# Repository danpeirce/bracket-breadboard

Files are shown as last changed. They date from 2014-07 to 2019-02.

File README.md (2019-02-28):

# PICkit2, PICkit3 Programming Header to Breadboard Bracket (Master Branch - Arms removed)

This version of the README.md file will be updated with new photos as they becom available.

## Purpose of the bracket-breadboard SCAD Project
In APSC1299 and PHYS1600 a six pin programming header must be attached to a solderless breadboard. In the past this has been done with hot glue as a quick simple solution. A better long term solution is desirable. The last time I needed a bracket I turned to having it 3D printed and was happy with the result. This project lends itself nicely to 3D printing because the bracket will be small with fine features.

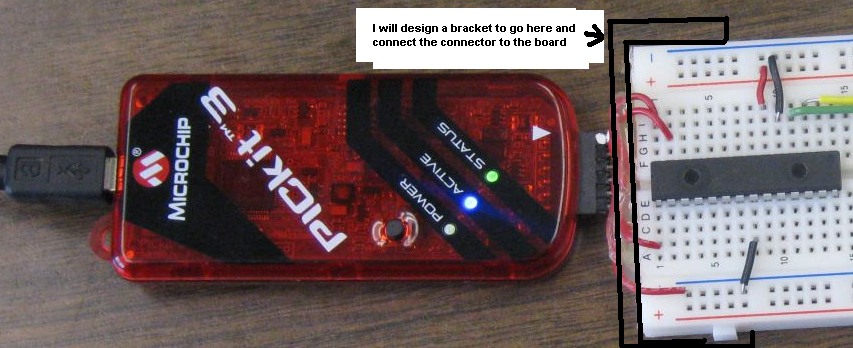
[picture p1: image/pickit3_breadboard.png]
PICkit2, PICkit3 Programming header to Breadboard Bracket


Final Version (to reduce cost attachment arms were left out)

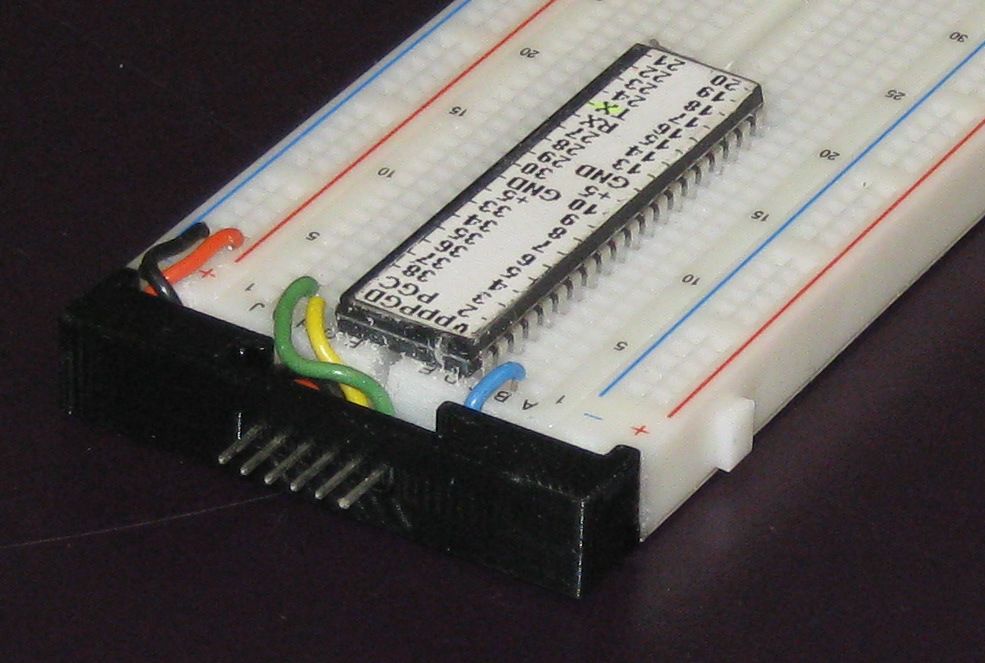
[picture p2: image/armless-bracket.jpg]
Image of final version without attachment arms


Image of prototype

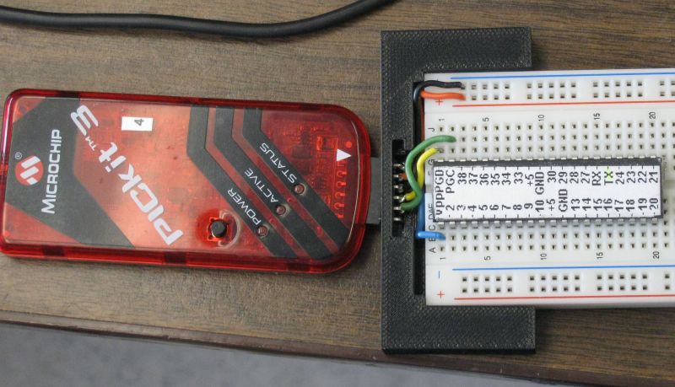
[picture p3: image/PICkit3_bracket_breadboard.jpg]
Bracket Top Back


## Creating a 3D Model using OpenSCAD

OpenSCAD is an free open source program that can be used for creating and viewing 3D models.

* [My notes on OpenSCAD including links](https://danpeirce.github.io/openscad.html)

### The Model

This image is from the second version of the SCAD file
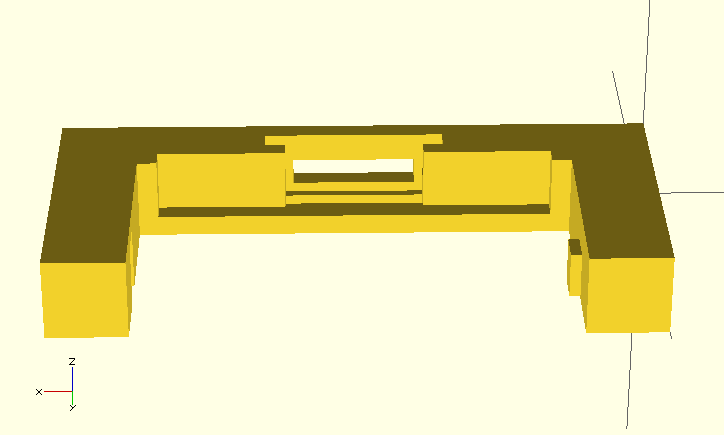
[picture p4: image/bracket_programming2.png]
bracket programming V2


These images are from the [first version of the SCAD file](https://github.com/danpeirce/bracket-breadboard/blob/c5ccfa7ed66dbcf597f41a93814c27feb3500029/bracket_programming.scad).

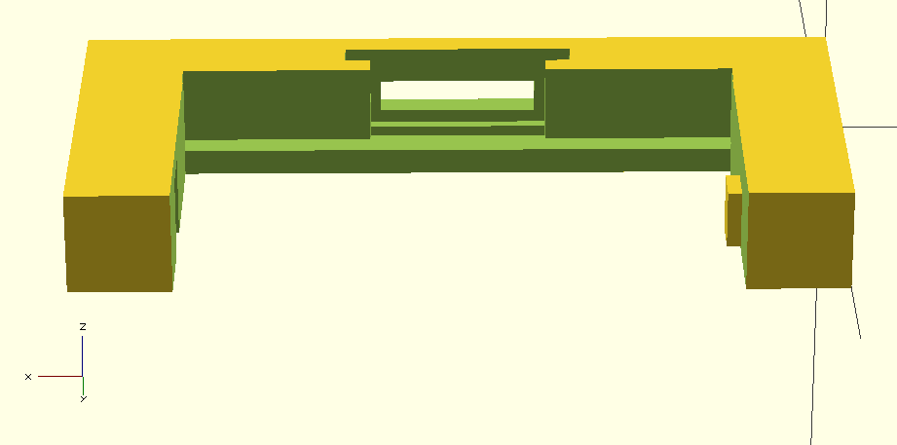
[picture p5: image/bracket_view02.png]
Bracket View 02


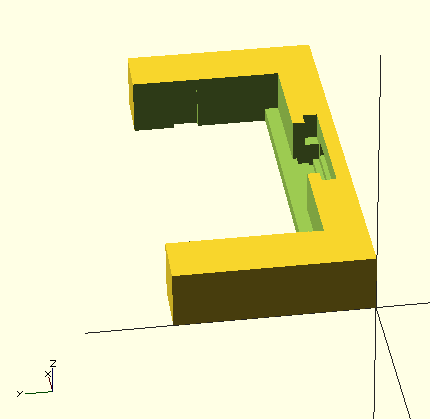
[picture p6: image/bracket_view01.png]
Bracket View 01


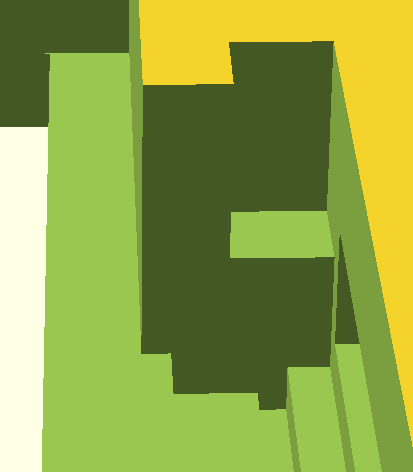
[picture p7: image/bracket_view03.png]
Bracket View 03


## Amended Procedure of adding Header and Wire

In 2016 the procedure for adding the header and wire was Amended to speed up the process.

In interest of keeping new programming header mounting method more time efficient and at the same time keeping 
the final result essentially unchanged I have worked out the following procedure/method (still using the existing 
3D printed part):

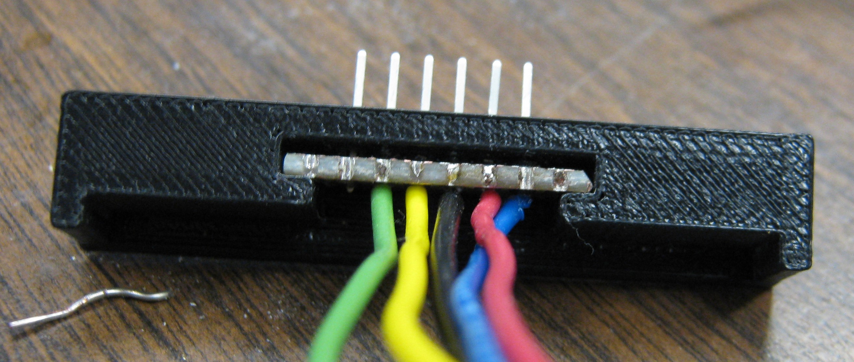
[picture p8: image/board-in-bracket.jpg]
board-in-bracket


I then mount it with hotglue so it can be removed the next time the breadbaord needs to be replaced:

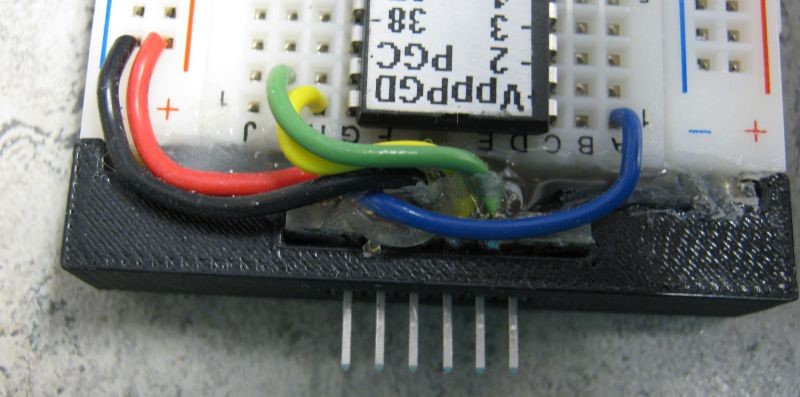
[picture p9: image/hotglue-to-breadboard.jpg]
hotglue-to-breadboard


The other change that helps get this together faster than before is the addition of a small piece of proto board 
and the change to straight header pins:

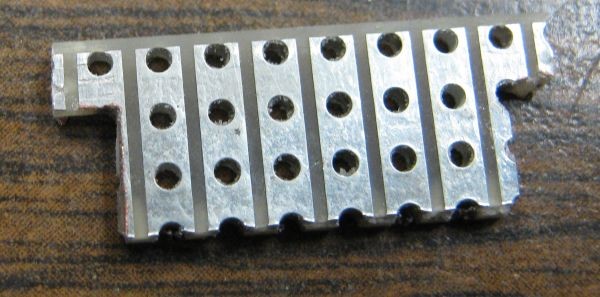
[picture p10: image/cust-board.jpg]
cust-board


* I solder the wires on first.
* Insert the header into the 3d printed addaptor.
* Then solder the header pins.

This way one can avoid twisting the wire onto each pin and crimping which is what I did before. 

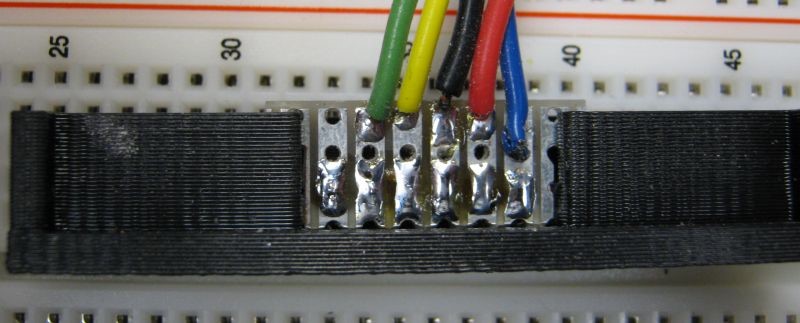
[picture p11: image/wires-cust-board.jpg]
wires-cust-board


## Prototype
 
These are the first images of the prototype that has been 3D printed in the KPU drafting department.
 
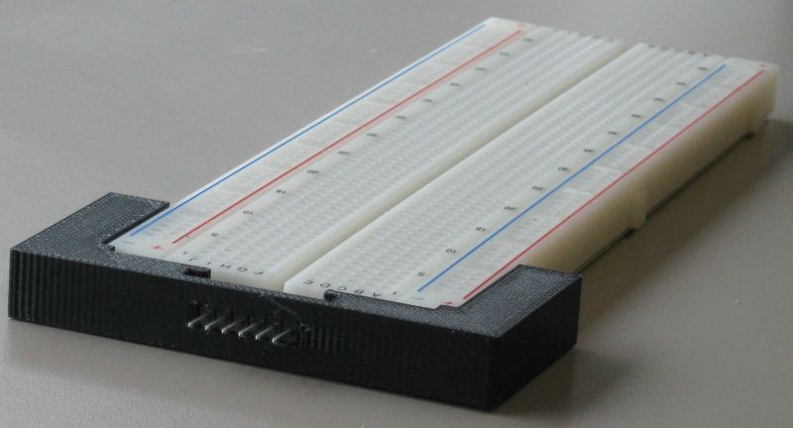
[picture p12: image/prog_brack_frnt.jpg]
Bracket Top Front


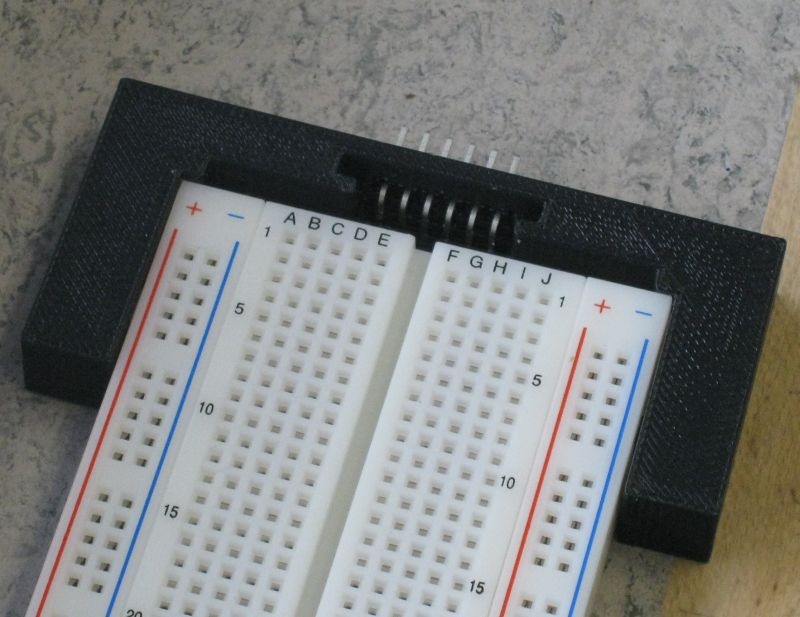
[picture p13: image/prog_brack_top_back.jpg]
Bracket Top Back
 

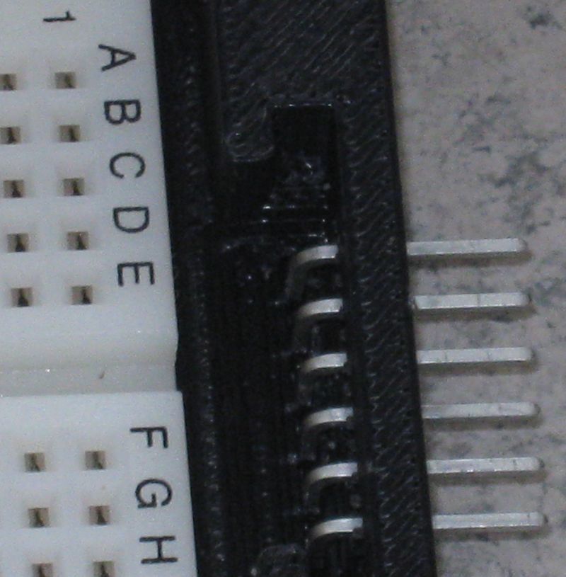
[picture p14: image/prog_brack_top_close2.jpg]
Connector Close2


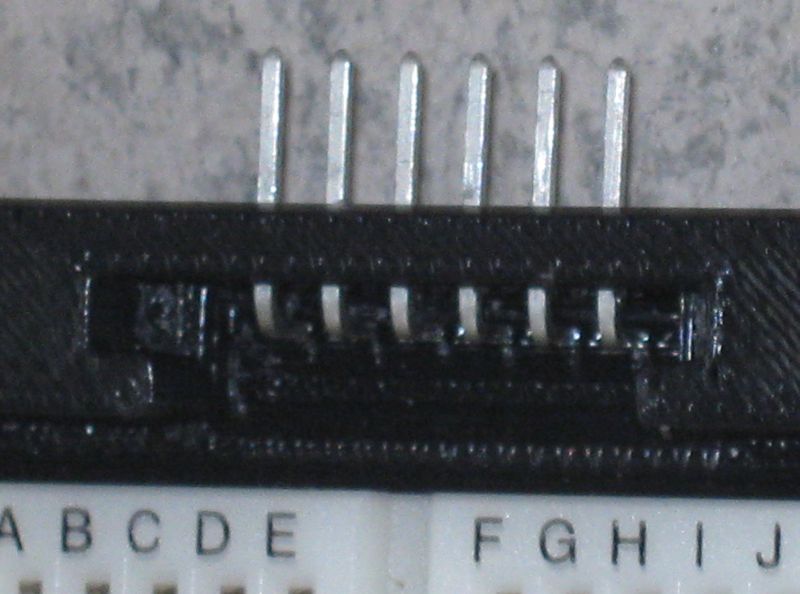
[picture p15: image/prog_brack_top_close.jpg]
Connector Close


## Soldering Wire Onto the Programming Header

The end of the hookup wire was bent in a loop and crimped onto the pins below the bend of in each pin. Solder was applied.

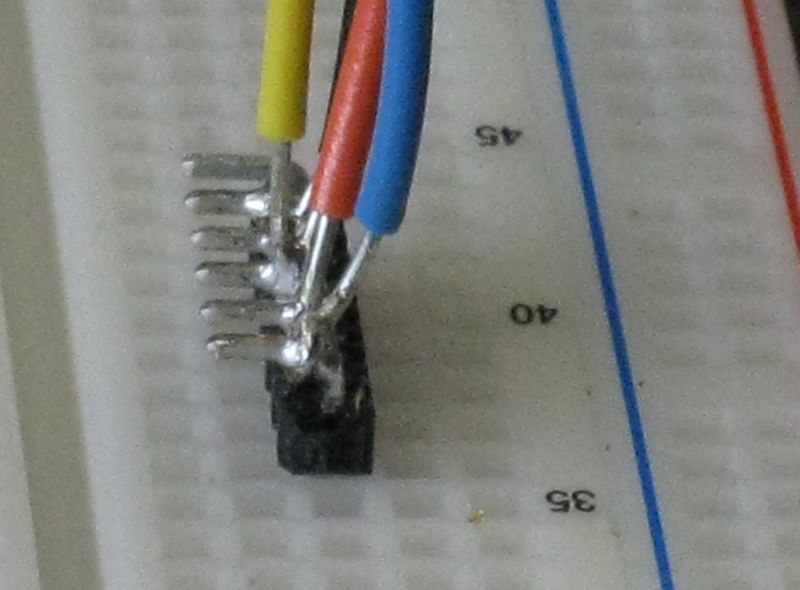
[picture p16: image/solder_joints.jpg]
Solder Joints


Once the wire was cool the insulation was slipped down to insulate the wire up to the solder joint.

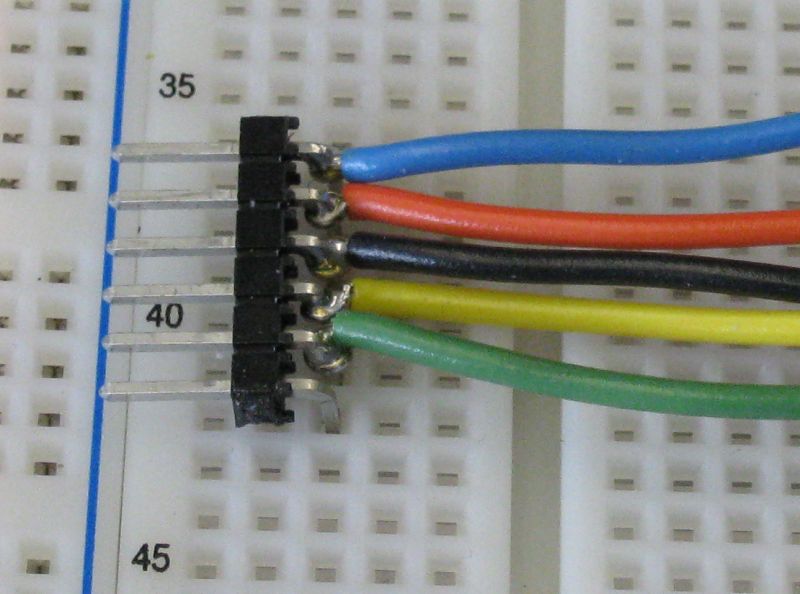
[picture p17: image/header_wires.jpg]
Adjust Header Wire Isolation


The header is inserted into the bracket from the back.

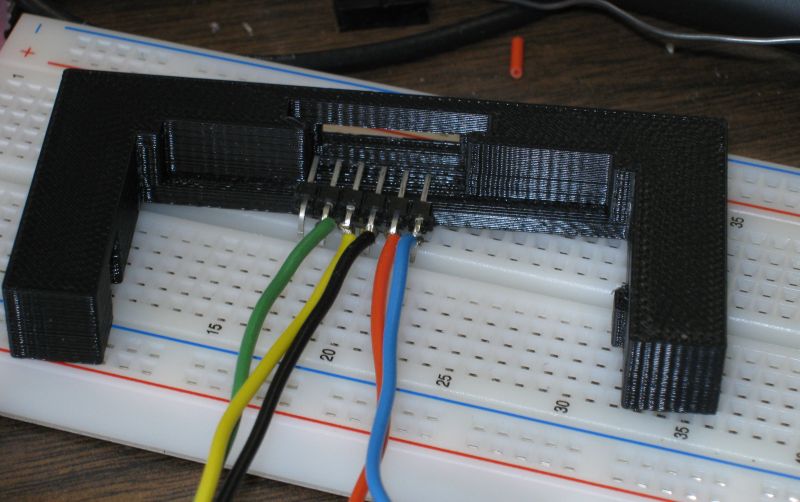
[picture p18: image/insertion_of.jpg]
Inserting Header


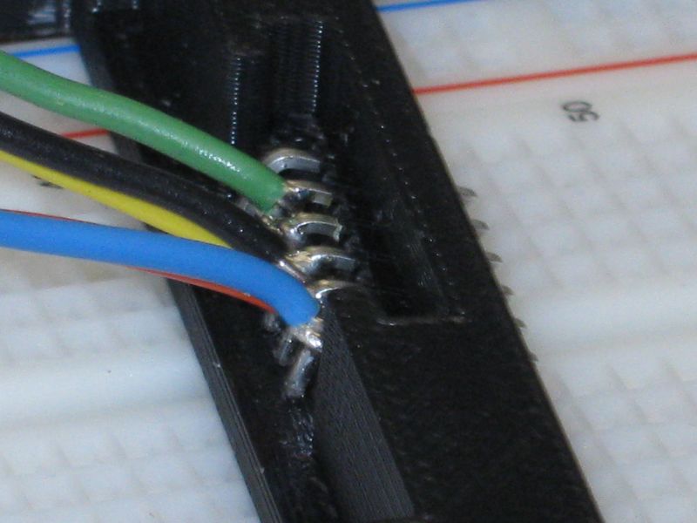
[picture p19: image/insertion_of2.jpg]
Inserting Header 2


The end of the pins are snapped into place with a small flat screwdriver (they fit into a shallow narrow slot).

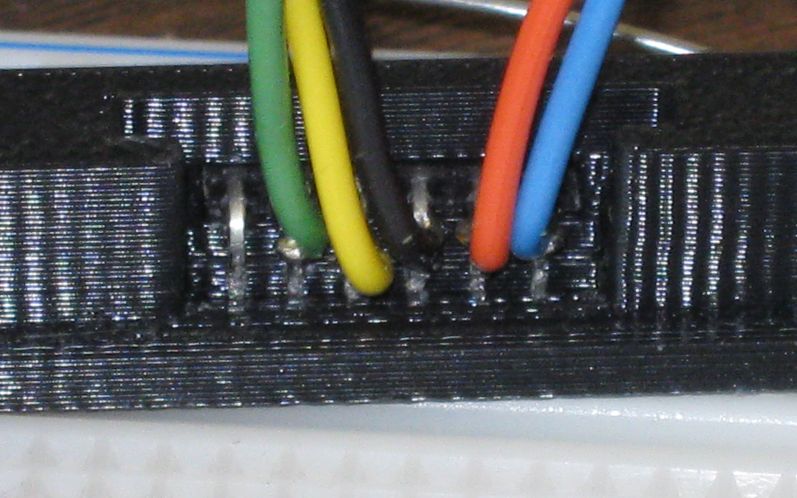
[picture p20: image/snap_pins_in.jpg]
Pins snapped into place


The bracket is twisted onto the board until it snaps in place.

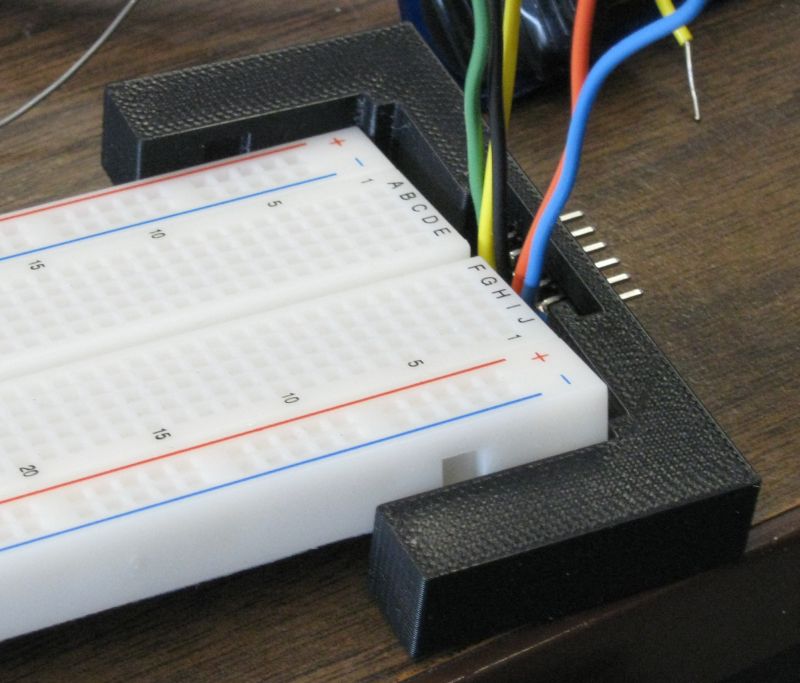
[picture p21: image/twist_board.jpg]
Bracket twisted onto board


The placement of the wire is adjusted.

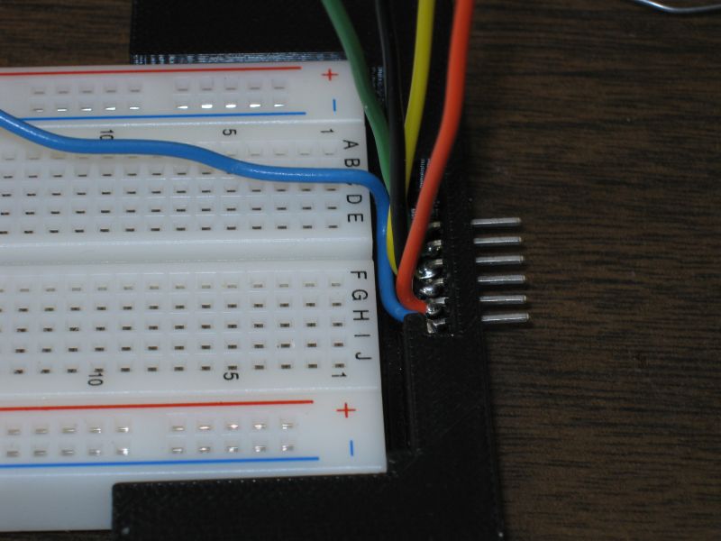
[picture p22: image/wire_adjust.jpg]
Placement wire adjusted


The rest of the wires are placed into the grove, trimmed and stripped to complete connections.

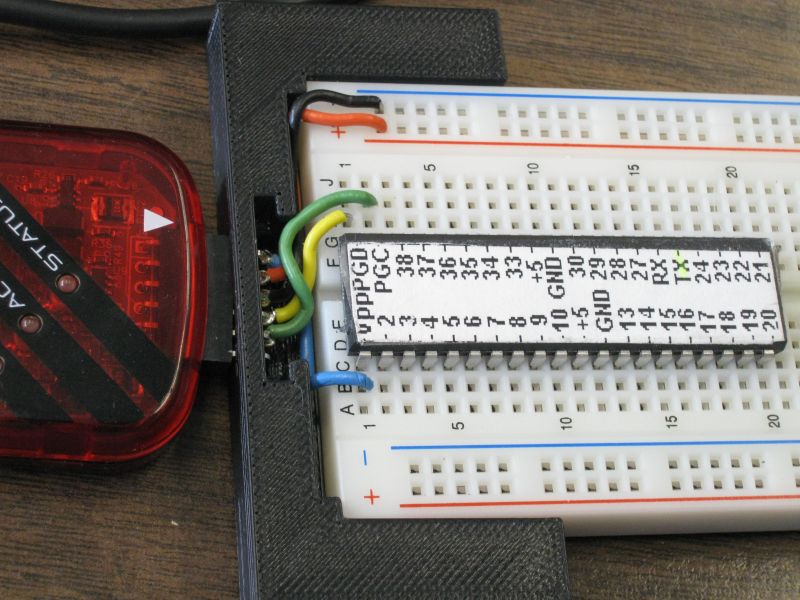
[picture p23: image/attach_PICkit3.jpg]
Completed connections


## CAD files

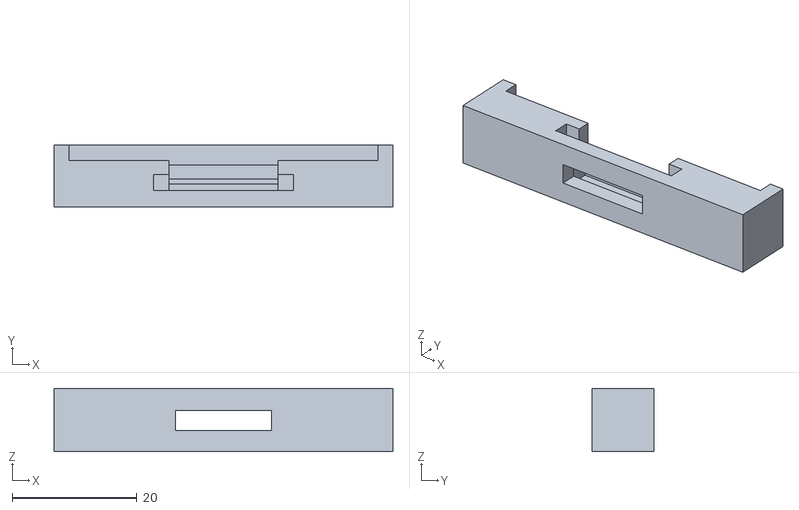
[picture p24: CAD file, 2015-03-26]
bracket_prog_short.stl
54.3 x 10.0 x 10.2

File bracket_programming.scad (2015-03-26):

// bracket_progamming.scad
// Dan Peirce B.Sc. cc0

inch = 25.4;
pin_width = 0.65;
back_offset = 1.52 - pin_width/2;
pitch = 2.54;
con_thk = 3.06+0.2; // measured April 16, 2014

con_length  = 6*pitch+0.22;
tail =2.54;
board_wd = 54.22 + 0.1;
arm_wd = 10;

x_slot_edge = board_wd/2-con_length/2-7/2+arm_wd;

tab_y =17.2;
tab_yh = 16.9;
tab_y_w = 4.4;
tab_x_w = 1.5;   
tabhole_y_w = 4.1;

difference()
{
    cube([board_wd+2*arm_wd, arm_wd, 0.4*inch]);

    translate([-0.1, -0.1, -0.1])
        cube([arm_wd+0.1, arm_wd+0.1*2, 0.4*inch+0.1*2]);
    translate([board_wd+arm_wd, -0.1, -0.1])
        cube([arm_wd+0.1, arm_wd+0.1*2, 0.4*inch+0.1*2]);

    translate([board_wd/2-con_length/2+arm_wd, -1, arm_wd/2-con_thk/2])
    {
         cube([con_length, 1+2.54+2, con_thk]);
    }   // space for body  of connector
    translate([board_wd/2-con_length/2-2/2+arm_wd, 2.54+back_offset, arm_wd/2-con_thk/2 - tail])
    {
         cube([con_length+2, pin_width+0.1, 12]);
    }   // space for tail   of connector and access
    translate([board_wd/2-con_length/2-2/2+arm_wd, 2.54+0.1, arm_wd/2-con_thk/2 - tail/2])
    {
         cube([con_length+2, 2.54+0.1, 12]);
    }   // space for solder connections


    translate([x_slot_edge, 2.54+0.1, arm_wd/2+pin_width/2])
    {
         cube([con_length+7, 2.54+0.1, 12]);
    }   // slot for insert

    translate([10-0.1+2.54, 7.5, 2.54])
    {
         cube([con_length+3.5, 2.54+0.1, 12]);
    }   // slot1 for wires
    translate([board_wd+arm_wd-(con_length+3.5)+0.1-2.54, 7.5, 2.54])
    {
         cube([con_length+3.5, 2.54+0.1, 12]);
    }   // slot2 for wires




    translate([board_wd/2-con_length/2-2/2+arm_wd, 2.54+back_offset , arm_wd/2-con_thk/2 - tail+0.5])
    {
         cube([con_length+2, 3, 12]);
    }   // space for access             
    translate([board_wd/2-con_length/2-2/2+arm_wd, 2.54+back_offset , 2.54])
    {
         cube([con_length+2, 10, 12]);
    }   // space for access 
}

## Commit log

2014-04-27 new file: bracket_programming.scad
    [bracket_programming.scad]
2014-04-27 modified: bracket_programming.scad shortened slots for wires to increase contact area with breadboard
    [bracket_programming.scad]
2014-04-30 modified: README.md
    Added link to STL file
2014-04-30 modified: README.md
    Added note to STL file link
2014-04-30 modified: README.md
    Added link to image of Ver2 of the Bracket
2014-05-22 Update README.md
    Added images of Bracket prototype that was printed by KPU Drafting Department.
2014-05-22 Update README.md
    Added images showing wires soldered onto programming header, how header is inserted into bracket, how bracket is snapped onto board and final wire connections.
2014-05-30 adjusted bracket-breadboard.scad based on measurments of prototype
    [bracket_programming.scad]
2014-05-30 Update README.md
    Changed link near top of readme.md to newest version of the STL file. Note the repository here contains the OpenSCAD source file *.scad but the STL files which are compiled from the source file are n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
2014-06-05 Removed attachment arms.
    modified: bracket_programming.scad
    [bracket_programming.scad]
2014-07-05 Update README.md
    Added new image showing bracket mounted without attachment arms.
2014-07-13 moved images to repository modified: README.md new file: image/PICkit3_bracket_breadboard.jpg new file: image/armless-bracket.jpg new file: image/attach_PICkit3.jpg new file: image/bracket_programmin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
2014-11-16 added comments
    [bracket_programming.scad]
2015-03-26 included stl file
    [bracket_prog_short.stl]
